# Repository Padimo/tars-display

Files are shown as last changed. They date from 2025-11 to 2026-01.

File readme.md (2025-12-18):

# TARS Quote

A miniature TARS with an OLED display that shows text that is sent to it via Firebase. 
A close friend of mine is a huge Interstellar fan, so I'm making this for her. 

### Features
- Show quote
	- From multiple people
	- Tracked with Firebase? I've used it before with ESP32 so should be straightforward
	- *Requires: ESP32, 0.96" OLED*
- Scroll if longer quotes
	- *Requires: EC11 rotary encoder (with button because why not)*

### Hardware

The TARS Quote device utilizes a three-part PCB. One part breaks out the USBC port so that it can be angled, a second is the main board with controls, and then the third board is a charlieplexed matrix of the TARS Braille dots.
The brains of this board is the ESP32S3-WROOM-1-N4. The display is a Waveshare SSD1331. The arms are moved by two standard blue 9g servos. Power and programming data come from USBC, and is stepped down using an AP2112K-3.3TRG. Standard 0805 LEDs and WS2818B LEDs compose the internal lighting of the system. Inputs come from a D-pad manufactured by Sparkfun. Speaker amplifier is a MAX98357A I2S IC. 

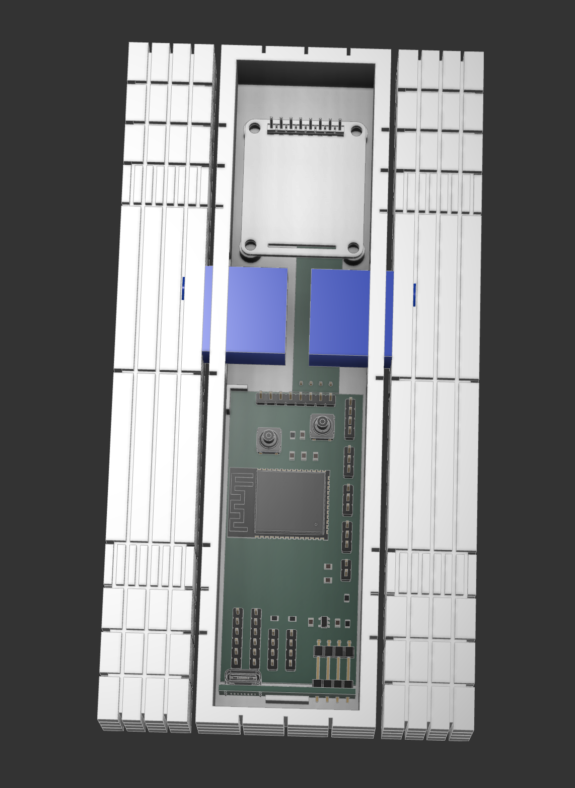
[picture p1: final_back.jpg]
Final image

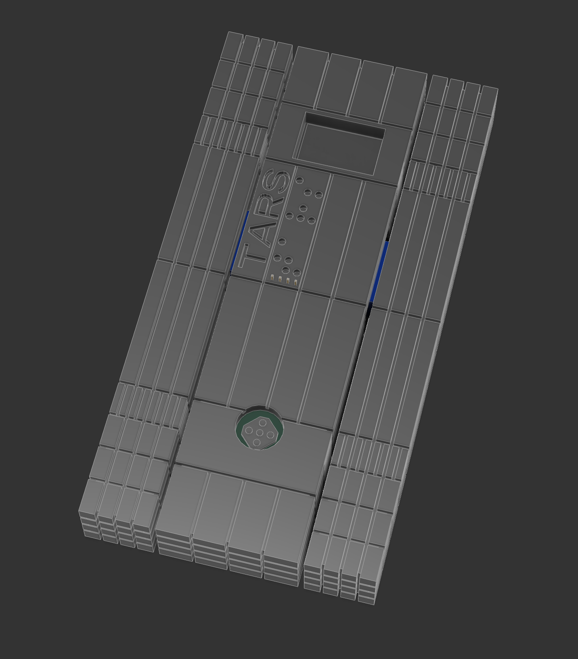
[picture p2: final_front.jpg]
Final image


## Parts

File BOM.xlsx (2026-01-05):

Component | Quantity | Price | Total price | Vendor | Link | Notes | In cart? | Vender cost with shipping | Ordered? | Received?
PCB | 1 |  | $0.00 | JLCPCB | https://cart.jlcpcb.com/quote | Upload Gerbers | Yes | $6.22 | Yes | No
ESP32S3 WROOM 1 N4 | 1 | $5.06 | $5.06 | Digikey | https://www.digikey.com/en/products/detail/espressif-systems/esp32-s3-wroom-1-n4/16162639 | add shipping | Yes | $25.82 | Yes | No
USBC Receptacle | 1 | $0.88 | $0.88 | Digikey | https://www.digikey.com/en/products/detail/gct/USB4085-GF-A/9859662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 | add shipping | Yes | $25.82 | Yes | No
MAX98357A Amplifier | 1 | $3.19 | $3.19 | Digikey | https://www.digikey.com/en/products/detail/analog-devices-inc-maxim-integrated/max98357aete-t/4936122 | add shipping | Yes | $25.82 | Yes | No
AP2112K 3.3V regulator | 1 | $0.22 | $0.22 | Digikey | https://www.digikey.com/en/products/detail/diodes-incorporated/ap2112k-3-3trg1/4470746 | add shipping | Yes | $25.82 | Yes | No
9g servo | 2 | $7.49 | $7.49 | Amazon | https://www.amazon.com/Micro-Servos-Helicopter-Airplane-Controls/dp/B07MLR1498/ | add shipping | Yes | $59.84 | Yes | No
SSD1331 OLED | 1 | $19.99 | $19.99 | Amazon | https://www.amazon.com/Waveshare-Resolution-Horizontal-Pinheader-Raspberry/dp/B0BFQF8GT3/ | add shipping | Yes | $59.84 | Yes | No
WS2812B LED Strip | 1 | $9.99 | $9.99 | Amazon | https://www.amazon.com/LOAMLIN-Individually-Addressable-144Pixels-Waterproof/dp/B0BDRCQWWQ/?th=1 | add shipping | Yes | $59.84 | Yes | No
Push buttons | 2 | $0.18 | $0.36 | Digikey | https://www.digikey.com/en/products/detail/cui-devices/TS04-66-50-BK-160-SMT/15634240 | add shipping | Yes | $25.82 | Yes | No
D Pad | 1 | $0.95 | $0.95 | Digikey | https://www.digikey.com/en/products/detail/sparkfun-electronics/COM-26850/26266463 | add shipping | Yes | $25.82 | Yes | No
Speaker | 1 | $5.37 | $5.37 | Digikey | https://www.digikey.com/en/products/detail/pui-audio-inc/AS04004PO-2-R/1745528 | add shipping | Yes | $25.82 | Yes | No
0805 capacitors | 8 | $0.00 | $0.00 | Myself |  |  |  | $0.00 | Yes | No
0805 resistors | 7 | $0.00 | $0.00 | Myself |  |  |  | $0.00 | Yes | No
0805 LEDs (blue) | 12 | $0.00 | $0.00 | Myself |  |  |  | $0.00 | Yes | No
3D Print | 1 | $0.00 | $0.00 | Myself |  |  |  | $0.00 | Yes | No
Heat inserts | 1 | $8.99 | $8.99 | Amazon | https://www.amazon.com/HANGLIFE-Heat-Set-Threaded-Printing-Components/dp/B0CS6VZYL8/ | add shipping | Yes | $59.84 | Yes | No
TOTAL |  |  | $62.49 |  |  |  |  | $91.88
Note: Price = 0 means that I already have parts and the cost should not be considered for Blueprint.

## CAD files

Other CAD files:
CAD/TARS Quote CAD v1.step

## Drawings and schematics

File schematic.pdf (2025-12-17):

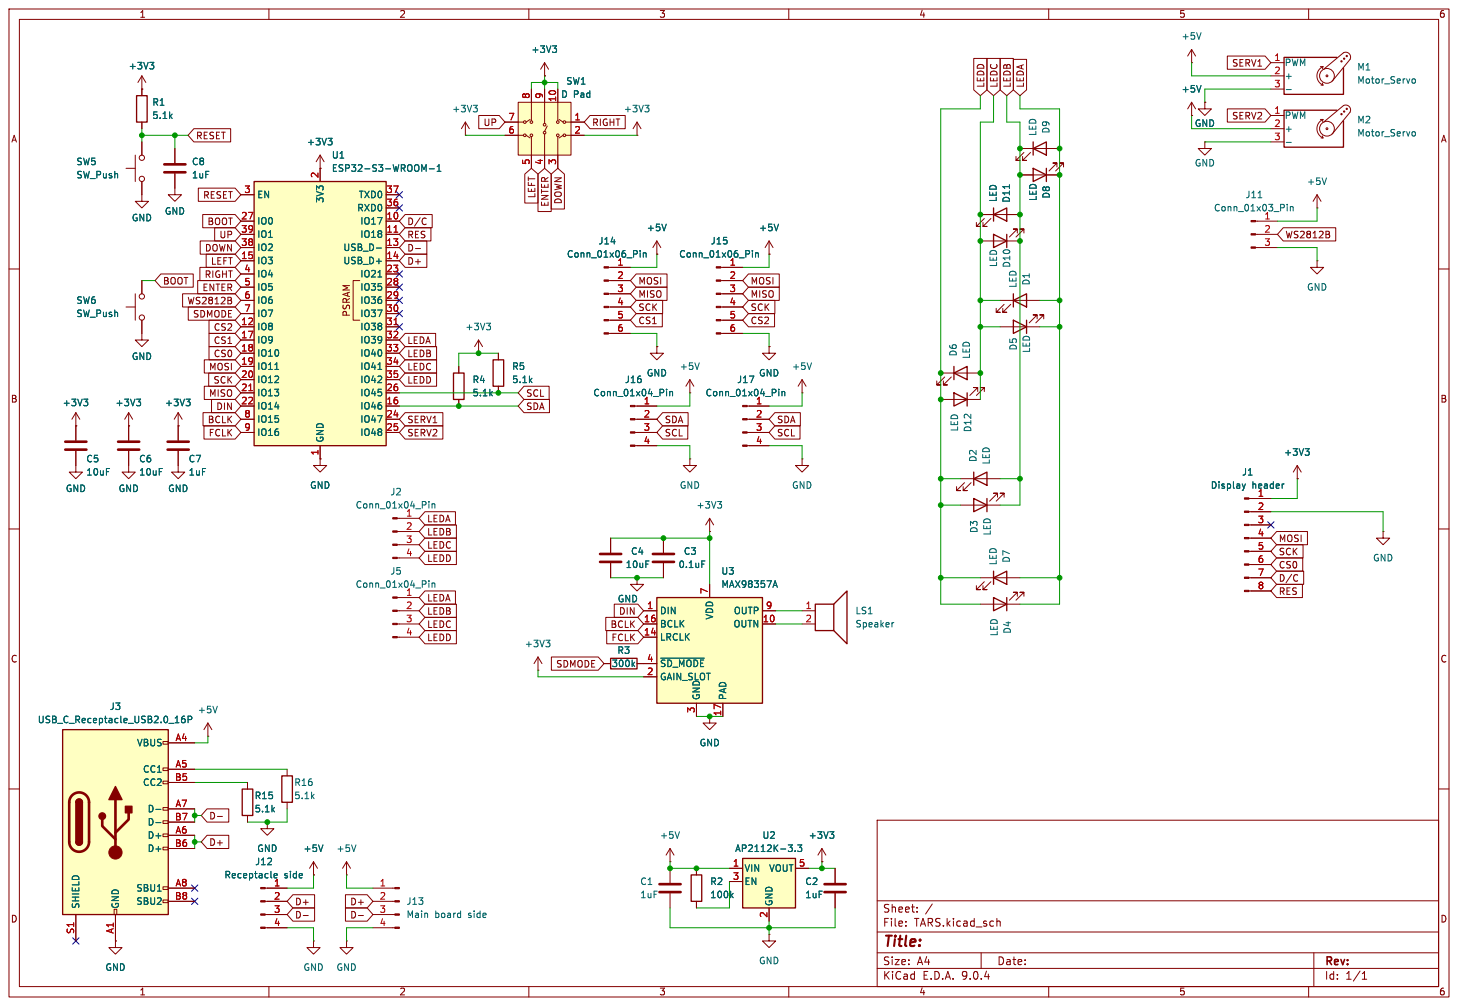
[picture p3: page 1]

7 PAD 17 OUTP 9 OUTN 10 U3 MAX98357A LED D8 R3

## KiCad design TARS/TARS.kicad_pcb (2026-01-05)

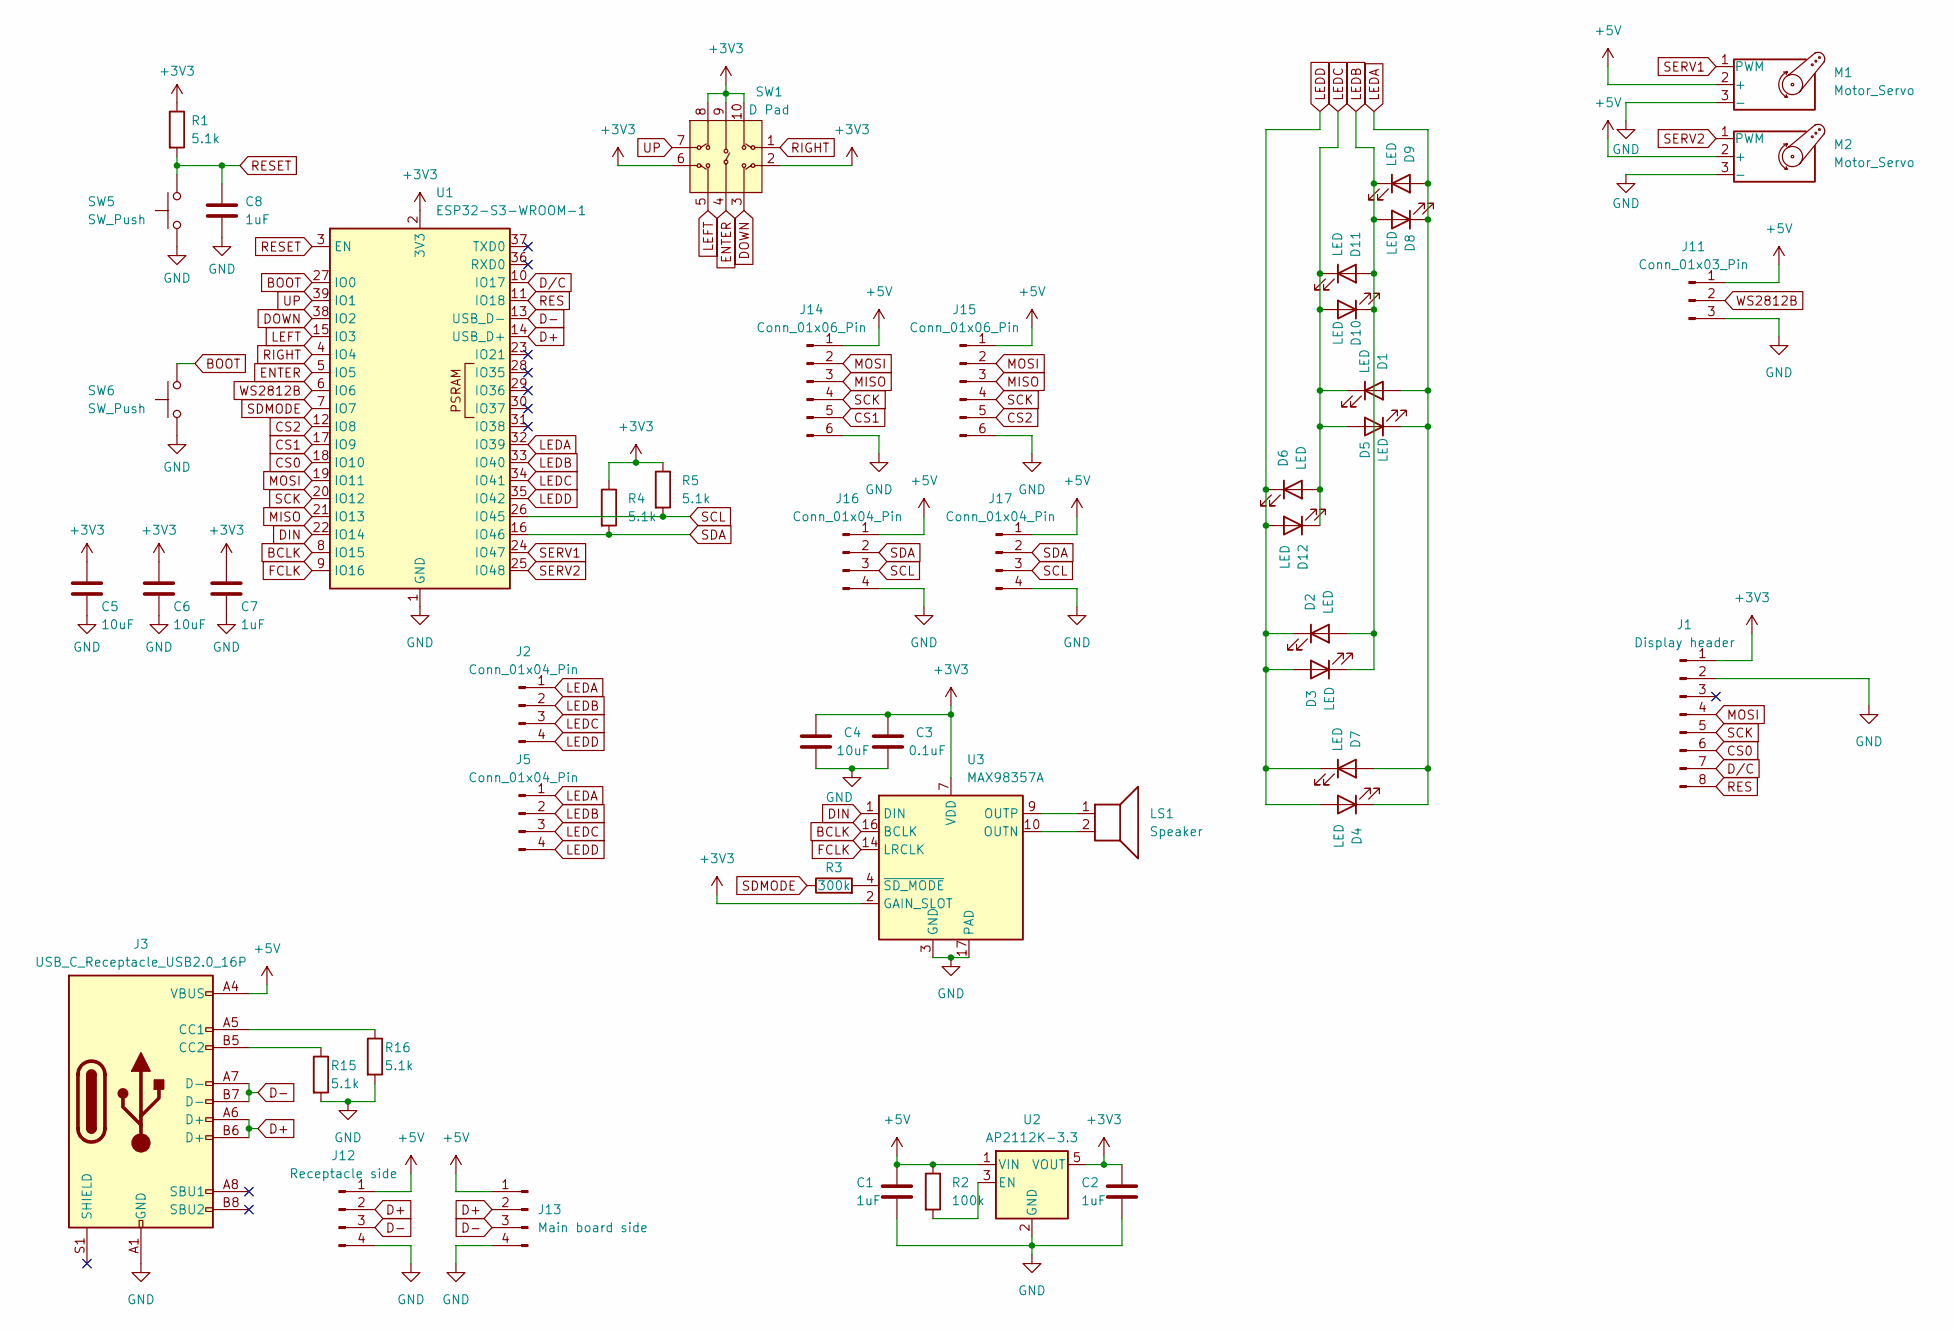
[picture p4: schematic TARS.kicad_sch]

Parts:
C1, C2, C7, C8: 1uF; C_0805_2012Metric
C3: 0.1uF; C_0805_2012Metric
C4, C5, C6: 10uF; C_0805_2012Metric
D1, D2, D3, D4, D5, D6, D7, D8, D9, D10, D11, D12: LED; LED_0805_2012Metric
J1: Display header; PinHeader_1x08_P2.54mm_Vertical
J2, J5, J16, J17: Conn_01x04_Pin; PinHeader_1x04_P2.54mm_Vertical
J3: USB_C_Receptacle_USB2.0_16P; USB_C_Receptacle_GCT_USB4085
J11: Conn_01x03_Pin; PinHeader_1x03_P2.54mm_Vertical
J12: Receptacle side; PinHeader_1x04_P2.54mm_Vertical
J13: Main board side; PinHeader_1x04_P2.54mm_Horizontal
J14, J15: Conn_01x06_Pin; PinHeader_1x06_P2.54mm_Vertical
LS1: Speaker; PinHeader_1x02_P2.54mm_Vertical
M1, M2: Motor_Servo; PinHeader_1x03_P2.54mm_Vertical
R1, R4, R5, R15, R16: 5.1k; R_0805_2012Metric
R2: 100k; R_0805_2012Metric
R3: 300k; R_0805_2012Metric
SW1: D Pad; COM-26850 D Pad
SW5, SW6: SW_Push; SW_Push_1P1T_NO_CK_KSC6xxJ
U1: ESP32-S3-WROOM-1
U2: AP2112K-3.3; SOT-23-5
U3: MAX98357A; TQFN-16-1EP_3x3mm_P0.5mm_EP1.23x1.23mm

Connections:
+3V3: C2.1, C3.1, C4.1, C5.1, C6.1, C7.1, J1.1, R1.1, R4.1, R5.1, SW1.2, SW1.6, SW1.8, SW1.9, SW1.10, U1.2 (3V3), U2.5 (VOUT), U3.2 (GAIN_SLOT), U3.7 (VDD), U3.8 (VDD)
+5V: C1.1, J3.A4 (VBUS), J3.A9 (VBUS), J3.B4 (VBUS), J3.B9 (VBUS), J11.1, J12.1, J13.1, J14.1, J15.1, J16.1, J17.1, M1.2 (+), M2.2 (+), R2.1, U2.1 (VIN)
BCLK: U1.8 (IO15), U3.16 (BCLK)
BOOT: SW6.2, U1.27 (IO0)
CS0: J1.6, U1.18 (IO10)
CS1: J14.5, U1.17 (IO9)
CS2: J15.5, U1.12 (IO8)
D+: J3.A6 (D+), J3.B6 (D+), J12.2, J13.2, U1.14 (USB_D+)
D-: J3.A7 (D-), J3.B7 (D-), J12.3, J13.3, U1.13 (USB_D-)
DIN: U1.22 (IO14), U3.1 (DIN)
DOWN: SW1.3, U1.38 (IO2)
D/C: J1.7, U1.10 (IO17)
ENTER: SW1.4, U1.5 (IO5)
FCLK: U1.9 (IO16), U3.14 (LRCLK)
GND: C1.2, C2.2, C3.2, C4.2, C5.2, C6.2, C7.2, C8.2, J1.2, J3.A1 (GND), J3.A12 (GND), J3.B1 (GND), J3.B12 (GND), J11.3, J12.4, J13.4, J14.6, J15.6, J16.4, J17.4, M1.3 (-), M2.3 (-), R15.2, R16.2, SW5.1, SW6.1, U1.1 (GND), U1.40 (GND), U1.41 (GND), U2.2 (GND), U3.3 (GND), U3.11 (GND), U3.15 (GND), U3.17 (PAD)
LEDA: D1.2 (A), D4.1 (K), D5.1 (K), D7.2 (A), D8.1 (K), D9.2 (A), J2.1, J5.1, U1.32 (IO39)
LEDB: D2.2 (A), D3.1 (K), D8.2 (A), D9.1 (K), D10.1 (K), D11.2 (A), J2.2, J5.2, U1.33 (IO40)
LEDC: D1.1 (K), D5.2 (A), D6.2 (A), D10.2 (A), D11.1 (K), D12.1 (K), J2.3, J5.3, U1.34 (IO41)
LEDD: D2.1 (K), D3.2 (A), D4.2 (A), D6.1 (K), D7.1 (K), D12.2 (A), J2.4, J5.4, U1.35 (IO42)
LEFT: SW1.5, U1.15 (IO3)
MISO: J14.3, J15.3, U1.21 (IO13)
MOSI: J1.4, J14.2, J15.2, U1.19 (IO11)
unnamed: J3.A5 (CC1), R16.1
unnamed: J3.B5 (CC2), R15.1
unnamed: R2.2, U2.3 (EN)
unnamed: LS1.2, U3.10 (OUTN)
unnamed: LS1.1, U3.9 (OUTP)
unnamed: R3.2, U3.4 (~SD_MODE)
RES: J1.8, U1.11 (IO18)
RESET: C8.1, R1.2, SW5.2, U1.3 (EN)
RIGHT: SW1.1, U1.4 (IO4)
SCK: J1.5, J14.4, J15.4, U1.20 (IO12)
SCL: J16.3, J17.3, R5.2, U1.26 (IO45)
SDA: J16.2, J17.2, R4.2, U1.16 (IO46)
SDMODE: R3.1, U1.7 (IO7)
SERV1: M1.1 (PWM), U1.24 (IO47)
SERV2: M2.1 (PWM), U1.25 (IO48)
UP: SW1.7, U1.39 (IO1)
WS2812B: J11.2, U1.6 (IO6)

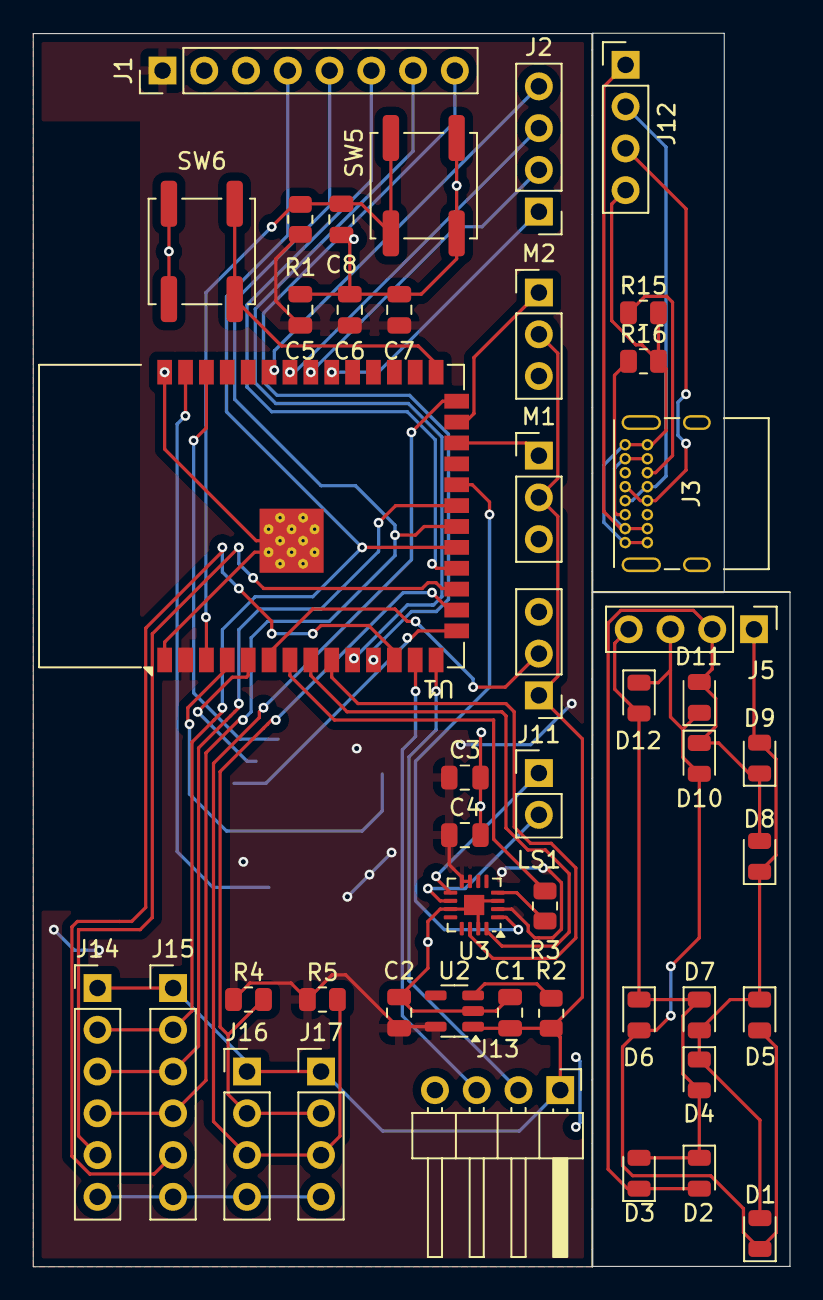
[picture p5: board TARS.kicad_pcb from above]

Board: 2 copper layers, 46.0 x 75.0 mm, 47 parts (1 on the bottom side), 39 nets.

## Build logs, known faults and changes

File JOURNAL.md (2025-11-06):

<!--
  ===================    !!READ THIS NOTICE!!   ====================
  DO NOT edit this file manually. Your changes WILL BE OVERWRITTEN!
  This journal is auto generated and updated by Hack Club Blueprint.
  To edit this file, please edit your journal entries on Blueprint.
  ==================================================================
-->

## 10/5/2025 - Brainstorm + Drawing  

##### TARS Quote
A heartfelt communication device based on the robot TARS from InterstellarScreenshot 2025-10-05 at 10.30.19 PM.png

This has been a vague idea brewing for a while, so first I brainstormed: 
### Features
- Show quote
	- From multiple people
	- Tracked with Firebase? I've used it before with ESP32 so should be straightforward
	- *Requires: ESP32, 0.96" OLED*
- Scroll if longer quotes
	- *Requires: EC11 rotary encoder (with button because why not)*
- Change position or walk
	- needs servos

###### Cool features that I might want to add (based on GPTARS):
- moving each of the four segments individually
- speaker so it can talk
- or microphone and speaker combo to make it walkie-talkie (but over WiFi)
- lights because LEDs make everything cooler

###### Other software features
- Auto dim at night
- Display on/off switch (will reset in the morning)
- LED patterns

I don't want to make it too complicated (yet) so that's all the features for now. 
Added features to readme. 

Made rough CAD drawings (2D) of the top face in Fusion, with dimensions. It occurs to me that if I want this thing to walk or at least have motors in the joints that actually do something, then I'll need some translational motion at least on the outer legs. That kind of assembly will be added because I want it to be able to walk  

## 10/6/2025 - CAD  

I normally start with the PCB but for this project I think it makes more sense for me to fit the PCB to the case (TARS not CASE) which means that I have to actually make the PCB. 

###### CAD
The drawing I started with was the entire top face but I actually need to separate it... so I have to split sketch or something. 

I started with the central piece, but then realized that the OLED I planned to use (0.95" SSD1331) is too big for what I'd drawn before. There's a really nice model of the robots here: https://www.thingiverse.com/thing:5156908 
So I used these dimensions to start (22x176x22mm). 
For the TARS lettering I found the font they used in the movie (Trade Gothic LT Std) and installed that. 

Here's the top face (center only)
Screenshot 2025-10-06 at 4.59.28 PM.png

Took me an hour to discover circular pattern + combine intersect for the side piece. Thank goodness I can rectangular pattern it to make the second one. 

Screenshot 2025-10-06 at 9.25.55 PM.png

Finished CAD for now. Will add arm servos for the side pieces later, and will fill in the rest of the central portion once a PCB and other electronics have been added.   

## 10/8/2025 - More Brainstorming  

Needed to document research/ideation.

##### Components and Features

#### Features
- Concretely: 
	- Show whatever text is in the Firebase on the display
	- Move legs (walking)
	- LED highlights (that's my specialty)
	- Memory to make a "log" (more on that later)
	- Show images from SD
	- Enable/disable name of whoever sent the text to the display (typically me, but could also be siblings and other friends etc.)
	- some personality, showing time and weather i suppose
- Maybe (if time permits):
	- Speech/conversations

#### Components
- ESP32 (preferably WROOM and not making everything myself, even though WROOM is probably more expensive for JLC SMT)
- 0.95" SSD1331 OLED
- 4x servo
- Neopixel LEDs
- SD card + reader
- Microphone/speakers? 
- Power management + power input port (I wanted battery but I don't think it'll work out)

OLED I'm using:
Screenshot 2025-10-08 at 9.46.56 PM.png  

## 10/13/2025 - Schematic design + CAD  

##### Schematic design: 
**Components**
- ESP32 WROOM
- 0.95" SSD1331 OLED
- 4x servo
- Neopixel LEDs
- SD card + reader
- Power management + power input port (I wanted battery but I don't think it'll work out)

Screenshot 2025-10-13 at 3.12.45 PM.png

To Do:
- Import SSD1331 into KiCad
- Servo calculations (are 9g ones strong enough)
- Neopixel patterns
- SD card reader location and storage needed
- Power management system
	- Power input (5-12V adapter from wall outlet, at least 2m length)
	- 5V regulator
	- 3.3V regulator
	- Logic level shifters 3.3V -> 5V (for 9g servos)

#### Servo calculations
Two of the servos will be rotating the outer legs; the other two will lift/lower legs enabling it to move effectively.
This means I have to design the lift mechanism so that I can do the calculations...

# Servo Lift Mechanism
Paused.  

## 11/5/2025 - More CAD (A)  

First I measured how much space I'll have for a PCB. I don't want it to take up too much space because I want to include WS2812B LEDs throughout the inside of the robot. (I have yet to figure out how to route them to the outer legs, where they'll be or what they'll even do.)

I have $44-2(4)=36mm$ max width.
I'll limit the length to half of the available space, so $(176-2(4))/2=84mm$ max length. 
I have 44/2-2(4)=14mm vertical height. This isn't as important to the PCB which will be 1.6mm thick, and I doubt other components will exceed an additional 5mm of height. The bulk of this space will likely be wiring. 

I also want to set each of the Braille dots in the main body to be illuminated. Since they're 2.5mm in diameter and WS2812B are 5mmx5mm I'll probably just use 0805 LEDs. 

Why PCB? Because I'm using ESP32S3-WROOM-1. I don't want to deal with a dev board. 

Hmm. Genius idea: add two I2C and two SPI expansion ports on the back just for fun. 

Components to be on the PCB: 
- ESP32S3-WROOM-1
- all power management circuitry
- Headers
	- Servo headers (x2 not x4)
	- Display headers 
	- Speaker headers (yes I will include a speaker)
- MEMS microphone? if I end up including it. I'll leave space for it for sure. 

While thinking (dangerous, I know) I have decided that the PCB is the MIDDLE half of the main body! Makes it easy, I can just put all headers at the top, and the OLED won't be pressed up against the PCB. 

More thinking: I need inputs. Silly me! The ESP32 has built in capacitive touch channels so all I need to do are break these out (probably on the bottom). 

Even more thinking: no need for servo lift mechanism because I don't want it to walk around if its tethered by a power cable anyway. 

Note: try to avoid QFN, BGA, etc. anything super difficult to solder with just a hot plate and no pick and place machine

Here's the input layout I came up with: 
Screenshot 2025-11-03 at 3.44.49 PM

The wide panel with arrows: the top middle will be up, bottom middle is down, left left, right right.
The stuff under: various positions the TARS can be in. The first one is just upright, the second one is leaning forward, the third one is one arm forward one back (probably I'll set which arm to be RNG) and the last one is to toggle sleep mode. Obviously on the actual model I can make it 3D so it will make more sense. 

For these inputs I should add indicator LEDs. These will all be the same color as the Braille LEDs, and I'm thinking blue. 

Didn't I say the PCB won't extend that far, you may ask? Yes, I did. And I changed my mind again. Now, the PCB will be three-quarters of the available space, so $176*3/4-4=128mm$ length. 

Time to get to PCB design! 

#### PCB design
First I add the ESP32 S3 and two servos. Then, an 8 pin header for the display. This is followed by the 16 LEDs. 8 capacitive touch inputs are also added (as a pin header). Three pins in a header are for WS2812B LEDs which will be added more specifically later on. These require 5V, so next I'll add some power management. 

I wonder if USB-C might be the best option for this project. That way there's only one input anyway. I'll use the GCT_USB4085, since that's THT and therefore will have a strong physical connection. The orientation of the board forces the port to be at the bottom, but I want it at the back, so I'll design a slim breakaway board (first time!). This breakaway will have to be SUPER compact (14mm max, estimated 6mm from board, gives 8mm which is exactly the length of the breakaway; may need to rethink the PCB orientation) and have screw holes (means heat inserts in the 3D print point and a removable back panel (magnetic???)).

Rethinking PCB orientation: I want the PCB to be flush with the front of the robot. But the LED indicators and capacitive touch panels need to be in the front, so the CAD will need cutouts for those. This gives me about 10mm for the USBC breakaway which is much more comfortable. 

^ these notes will be important considerations while drawing and routing the PCB. remember this is me thinking during schematics.

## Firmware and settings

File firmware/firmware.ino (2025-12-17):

const char* host     = "ESP-OTA"; // Used for MDNS resolution
const char* ssid     = "ssid";
const char* password = "password";

#include <WebOTA.h>

#define LED_PIN 2

// the setup function runs once when you press reset or power the board
void setup() {
	Serial.begin(115200);

	// initialize digital pin LED_PIN as an output.
	pinMode(LED_PIN, OUTPUT);

	init_wifi(ssid, password, host);

	// Defaults to 8080 and "/webota"
	//webota.init(80, "/update");
}

// the loop function runs over and over again forever
void loop() {
	int md = 1000;

	digitalWrite(LED_PIN, HIGH);
	webota.delay(md);
	digitalWrite(LED_PIN, LOW);
	webota.delay(md);

	webota.handle();
}

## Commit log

2025-10-06 Add first iteration of CAD to repo
    [TARS Quote CAD v1.step]
2025-12-16 add everything
    [BOM.xlsx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]
2025-12-16 Update Gerber
    [TARS-B_Cu.gbr, TARS-B_Mask.gbr, TARS-B_Paste.gbr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]
2025-12-16 update BOM
    [BOM.xlsx]
2025-12-16 update BOM, found d pad on digikey
    [BOM.xlsx]
2025-12-16 update mousebites
    [TARS-B_Cu.gbr, TARS-B_Mask.gbr, TARS-B_Paste.gbr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]
2025-12-17 update BOM with prices
    [BOM.xlsx]
2025-12-17 update gerbers and readme
    [BOM.xlsx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]
2025-12-17 added PDF schematic
2025-12-17 fix bom
    [BOM.xlsx]
2025-12-17 add exploded CAD view to readme
2025-12-18 full assembly
2026-01-05 update pcb (remove mouse bites)
    [TARS-B_Cu.gbr, TARS-B_Mask.gbr, TARS-B_Paste.gbr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]
2026-01-05 pcb silkscreen separation
    [BOM.xlsx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]
